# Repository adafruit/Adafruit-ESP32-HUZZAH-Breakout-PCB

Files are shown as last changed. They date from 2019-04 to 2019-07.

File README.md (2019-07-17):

## Adafruit HUZZAH32 PCB

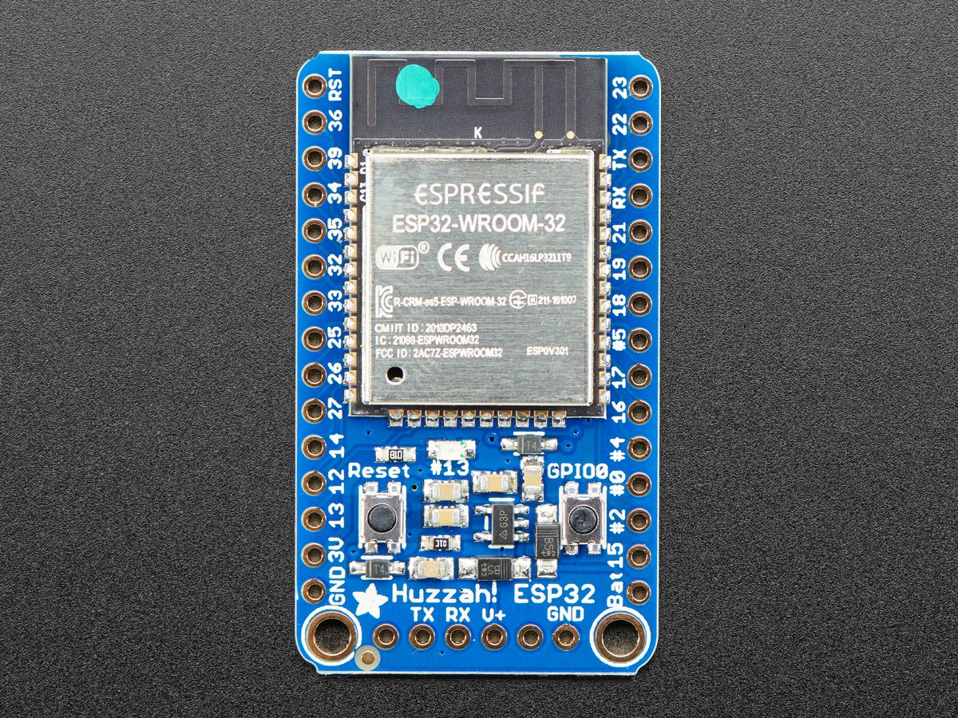
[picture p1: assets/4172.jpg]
<a href="http://www.adafruit.com/products/4172"><br/>
Click here to purchase one from the Adafruit shop</a>

PCB files for the Adafruit HUZZAH32. 

Format is EagleCAD schematic and board layout
* https://www.adafruit.com/product/4172

### Description

Squeeeeze down your next ESP32 project to its bare-bones essential with the **Adafruit HUZZAH32 Breakout**. This breakout is basically the 'big sister' of our HUZZAH 8266, but instead of an ESP8266 it has the '32! We've pared down our popular [Feather ESP32](https://www.adafruit.com/product/3405), removing the battery charger and USB-serial converter. You just get a regulator, some protection diodes, two buttons and an LED. For some projects, where price and size are at a premium, you can program this board over the 'FTDI cable' breakout when needed, and leave it alone otherwise.

Note that this board doesn't come with a USB to serial converter chip and auto-reset circuit. Instead, you will need to plug in a [CP2104 Friend](https://www.adafruit.com/product/3309) or [FTDI cable](https://www.adafruit.com/product/70). Then, before uploading code, put it into bootloader mode by holding down the GPIO #0 button and clicking Reset button, then releasing the #0 button.

That module in the middle of the breakout contains a dual-core ESP32 chip, 4 MB of SPI Flash, tuned antenna, and all the passives you need to take advantage of this powerful new processor. The ESP32 has both WiFi and Bluetooth Classic/LE support. That means it's perfect for just about any wireless or Internet-connected project.

The ESP32 is a perfect upgrade from the ESP8266 that has been so popular. In comparison, the ESP32 has way more GPIO, plenty of analog inputs, two analog outputs, multiple extra peripherals (like a spare UART), two cores so you don't have to yield to the WiFi manager, much higher-speed processor, etc. etc!

Comes fully assembled and tested, pre-programmed with ESP32 SPI WiFi co-processor firmware that [you can use in CircuitPython to use this into a WiFi co-processsor over SPI + 2 pins.](https://github.com/ladyada/Adafruit_CircuitPython_ESP32SPI) We also toss in some header so you can solder it in and plug into a solderless breadboard. 

Here are [specifications from Espressif about the ESP32](https://espressif.com/en/products/hardware/esp32/overview):

 * 240 MHz dual core Tensilica LX6 microcontroller with 600 DMIPS
 * Integrated 520 KB SRAM
 * Integrated 802.11b/g/n HT40 Wi-Fi transceiver, baseband, stack and LWIP
 * Integrated dual mode Bluetooth (classic and BLE)
 * 4 MByte flash include in the WROOM32 module
 * On-board PCB antenna
 * Ultra-low noise analog amplifier
 * Hall sensor
 * 10x capacitive touch interface
 * 32 kHz crystal oscillator
 * 3 x UARTs (only two are configured by default in the Feather Arduino IDE support, one UART is used for bootloading/debug)
 * 3 x SPI (only one is configured by default in the Feather Arduino IDE support)
 * 2 x I2C (only one is configured by default in the Feather Arduino IDE support)
 * 12 x ADC input channels
 * 2 x I2S Audio
 * 2 x DAC
 * PWM/timer input/output available on every GPIO pin
 * OpenOCD debug interface with 32 kB TRAX buffer
 * SDIO master/slave 50 MHz
 * SD-card interface support

### License

Adafruit invests time and resources providing this open source design, please support Adafruit and open-source hardware by purchasing products from [Adafruit](https://www.adafruit.com)!

Designed by Limor Fried/Ladyada for Adafruit Industries.

Creative Commons Attribution/Share-Alike, all text above must be included in any redistribution. 
See license.txt for additional details.

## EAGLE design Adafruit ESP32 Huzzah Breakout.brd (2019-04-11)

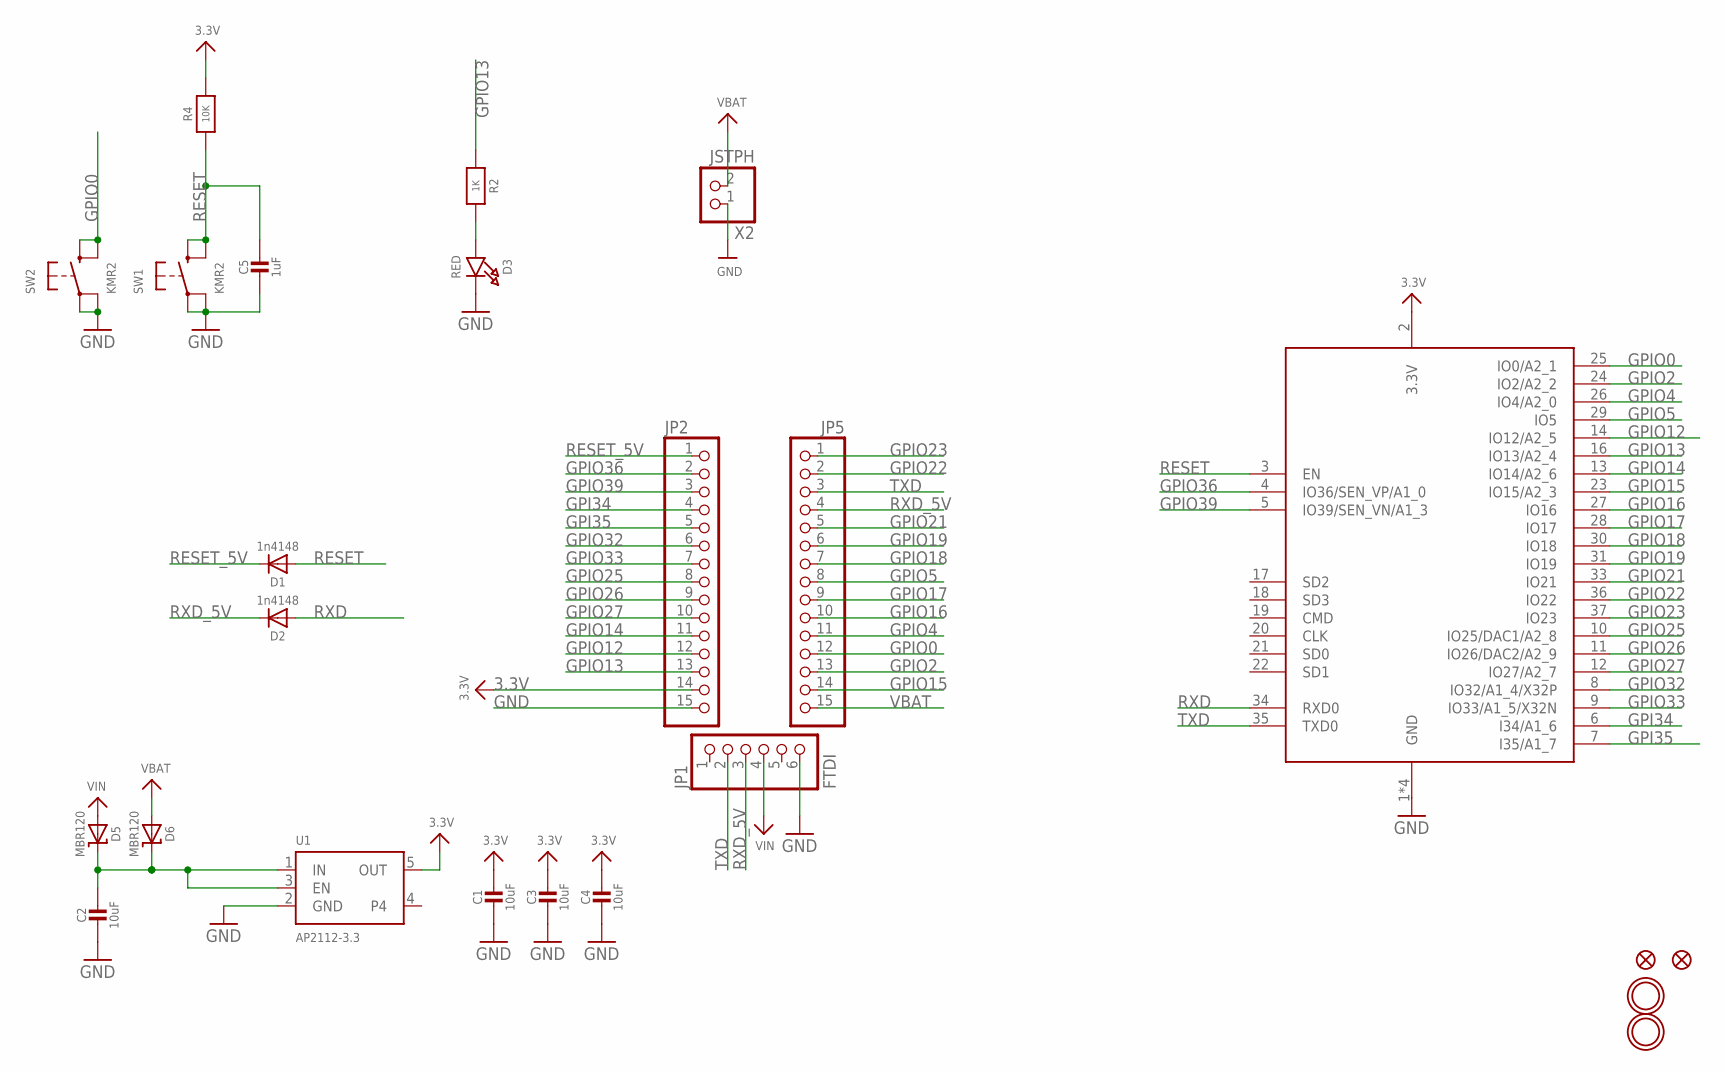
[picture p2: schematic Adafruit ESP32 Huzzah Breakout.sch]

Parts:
C1, C2, C3, C4: 10uF; 0805-NO
C5: 1uF; 0805-NO
D1, D2: 1n4148; SOD-323
D3: RED; CHIPLED_0805_NOOUTLINE
D5, D6: MBR120; SOD-123
FID1, FID3: FIDUCIAL_1MM
JP1: FTDI; 1X06_ROUND_70
JP2, JP5: HEADER-1X15; 1X15_ROUND_70
R2: 1K; 0603-NO
R4: 10K; 0603-NO
SW1, SW2: KMR2; BTN_KMR2_4.6X2.8
U1: AP2112-3.3; SOT23-5
U$15, U$16: MOUNTINGHOLE2.5; MOUNTINGHOLE_2.5_PLATED
X1: ESP32_WROOM32; WROOM32
X2: JSTPH; JSTPH2

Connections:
3.3V: C1.1, C3.1, C4.1, JP2.14, R4.2, U1.5 (OUT), X1.2 (3.3V)
GND: C1.2, C2.2, C3.2, C4.2, C5.2, D3.C, JP1.6, JP2.15, SW1.A, SW1.A' (P1), SW2.A, SW2.A' (P1), U1.2 (GND), X1.1 (GND), X1.15 (GND), X1.38 (GND), X1.P$1 (GND), X2.1
GPI34: JP2.4, X1.6 (I34/A1_6)
GPI35: JP2.5, X1.7 (I35/A1_7)
GPIO0: JP5.12, SW2.B (S), SW2.B' (S1), X1.25 (IO0/A2_1)
GPIO2: JP5.13, X1.24 (IO2/A2_2)
GPIO4: JP5.11, X1.26 (IO4/A2_0)
GPIO5: JP5.8, X1.29 (IO5)
GPIO12: JP2.12, X1.14 (IO12/A2_5)
GPIO13: JP2.13, R2.1, X1.16 (IO13/A2_4)
GPIO14: JP2.11, X1.13 (IO14/A2_6)
GPIO15: JP5.14, X1.23 (IO15/A2_3)
GPIO16: JP5.10, X1.27 (IO16)
GPIO17: JP5.9, X1.28 (IO17)
GPIO18: JP5.7, X1.30 (IO18)
GPIO19: JP5.6, X1.31 (IO19)
GPIO21: JP5.5, X1.33 (IO21)
GPIO22: JP5.2, X1.36 (IO22)
GPIO23: JP5.1, X1.37 (IO23)
GPIO25: JP2.8, X1.10 (IO25/DAC1/A2_8)
GPIO26: JP2.9, X1.11 (IO26/DAC2/A2_9)
GPIO27: JP2.10, X1.12 (IO27/A2_7)
GPIO32: JP2.6, X1.8 (IO32/A1_4/X32P)
GPIO33: JP2.7, X1.9 (IO33/A1_5/X32N)
GPIO36: JP2.2, X1.4 (IO36/SEN_VP/A1_0)
GPIO39: JP2.3, X1.5 (IO39/SEN_VN/A1_3)
LDO_EN: C2.1, D5.C, D6.C, U1.1 (IN), U1.3 (EN)
unnamed: D3.A, R2.2
RESET: C5.1, D1.A, R4.1, SW1.B (S), SW1.B' (S1), X1.3 (EN)
RESET_5V: D1.C, JP2.1
RXD: D2.A, X1.34 (RXD0)
RXD_5V: D2.C, JP1.3, JP5.4
TXD: JP1.2, JP5.3, X1.35 (TXD0)
VBAT: D6.A, JP5.15, X2.2
VIN: D5.A, JP1.4

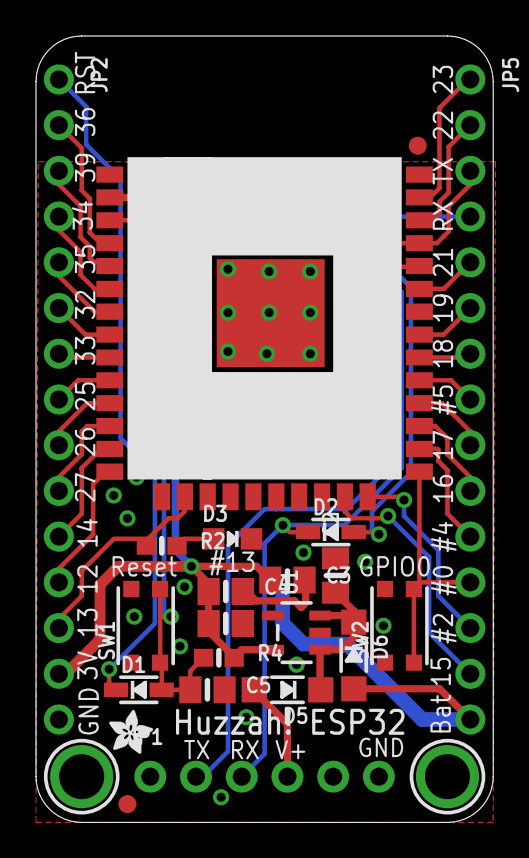
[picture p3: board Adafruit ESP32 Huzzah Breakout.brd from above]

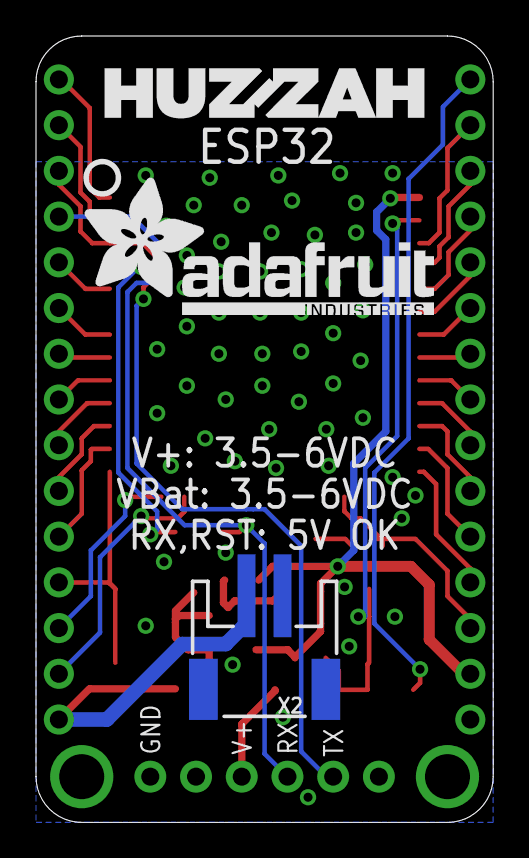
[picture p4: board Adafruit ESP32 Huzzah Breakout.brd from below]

Board: 2 copper layers, 25.4 x 43.7 mm, 28 parts (4 on the bottom side), 35 nets.

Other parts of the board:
U$2: HUZZAHLOGO
U$3: ADAFRUIT_2.5MM
U$12: ADAFRUIT_TEXT_20MM
U$13: PCBFEAT-REV-040

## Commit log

2019-04-11 Adding PCB files
    [Adafruit ESP32 Huzzah Breakout.brd, Adafruit ESP32 Huzzah Breakout.sch]
2019-07-17 updated to use cookiecutter for pcb repos

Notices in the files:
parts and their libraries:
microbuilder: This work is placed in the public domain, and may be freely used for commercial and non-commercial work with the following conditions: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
